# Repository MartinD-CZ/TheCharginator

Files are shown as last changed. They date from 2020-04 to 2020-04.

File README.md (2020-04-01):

# The CHARGINATOR
*Upcycle your old ATX power supply into this 11-port QC-compatible charging monstrosity!*
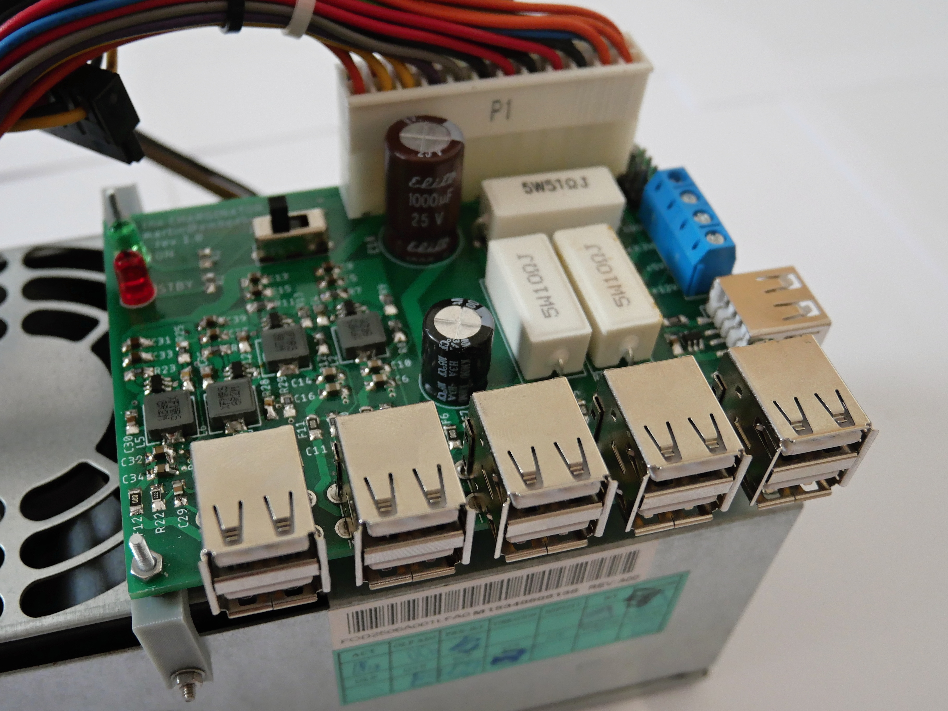
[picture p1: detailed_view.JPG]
Detailed view


Features:
* connects to an old PC power supply via a 24-pin MOLEX Mini-fit Jr. connector.
* provides power-on switch and LED, stand-by LED and three load resistors.
* 4 USB ports, compatible with QC3.0 (up to 24 W per port, 12 V 2 A), FCP (Huawei), DCP (Apple) and BCP (Battery Charging Protocol).
* 6 USB ports, compatible with DCP and BCP (5 V 2 A per port).
* 1 USB stand-by port, copatible with DCP and BCP (5 V 2 A per port).
* Each output individually fused with resetable fuse.
* Also, screw terminals with 3.3, 5 and 12 V are available.

Links:
* [Hackaday article]()
* [Article on my blog, explaining how the QC part works](http://embedblog.eu/?p=504)
* [FP6601 datasheet](https://datasheet.lcsc.com/szlcsc/Fitipower-Integrated-Tech-FP6601QS6_C86198.pdf)

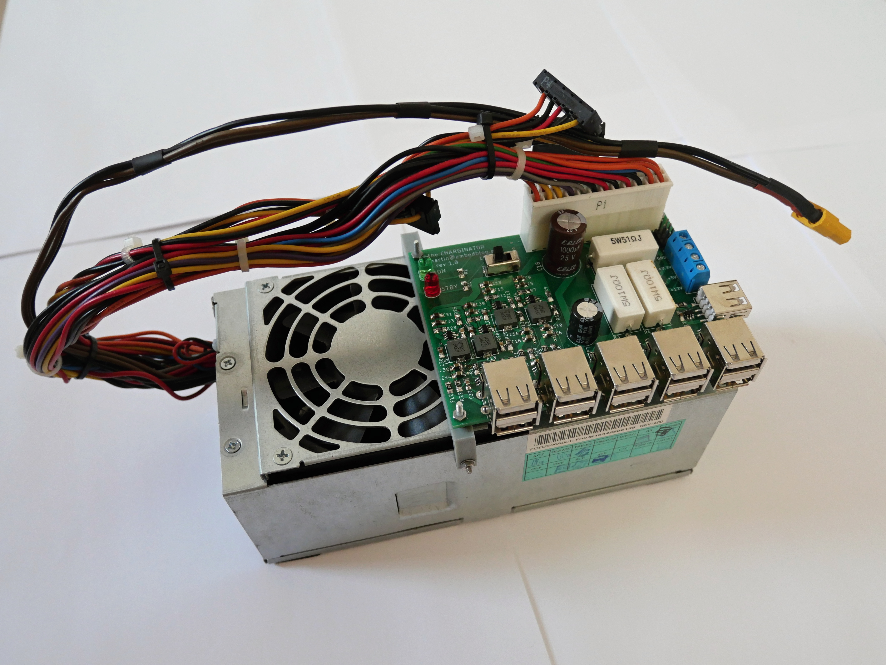
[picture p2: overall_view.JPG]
Overall view


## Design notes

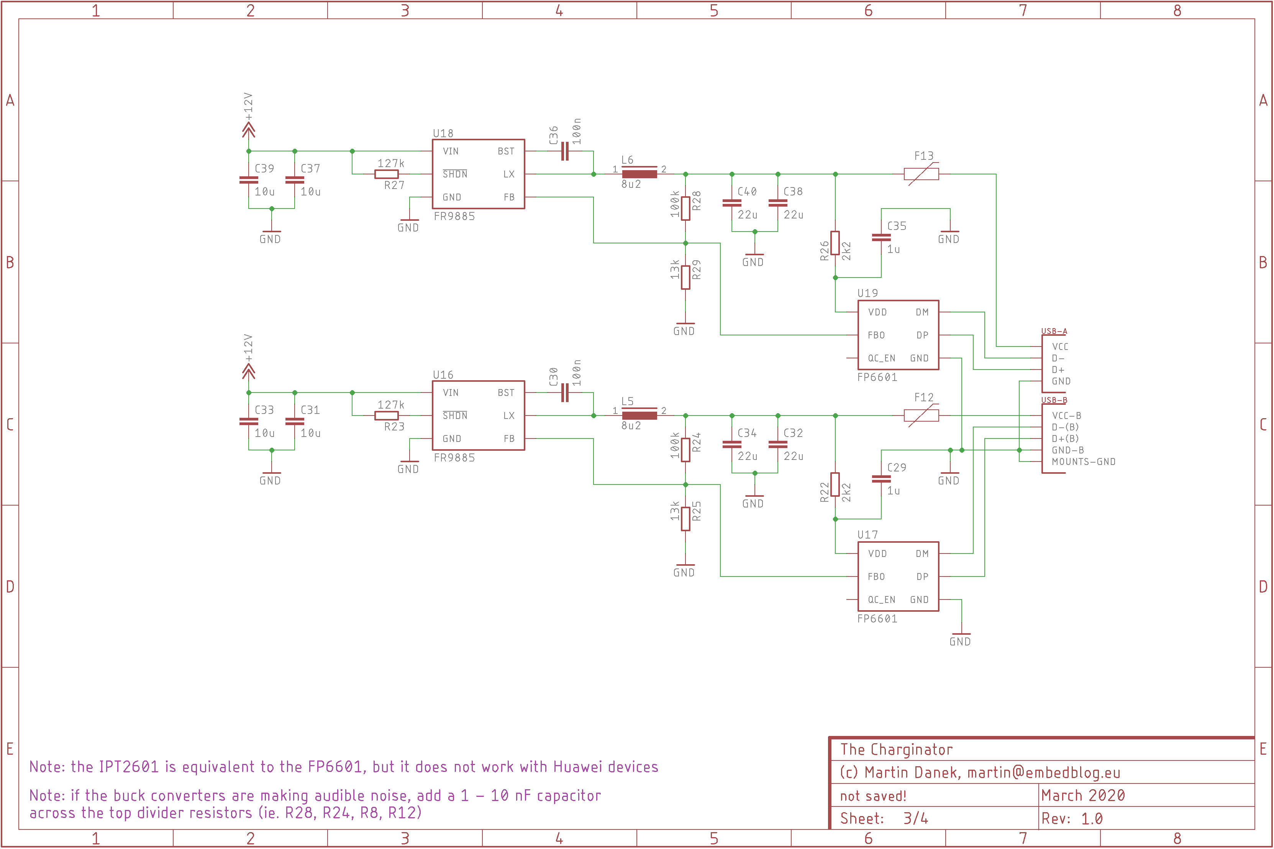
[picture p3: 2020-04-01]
schematics_png/sheet3.png

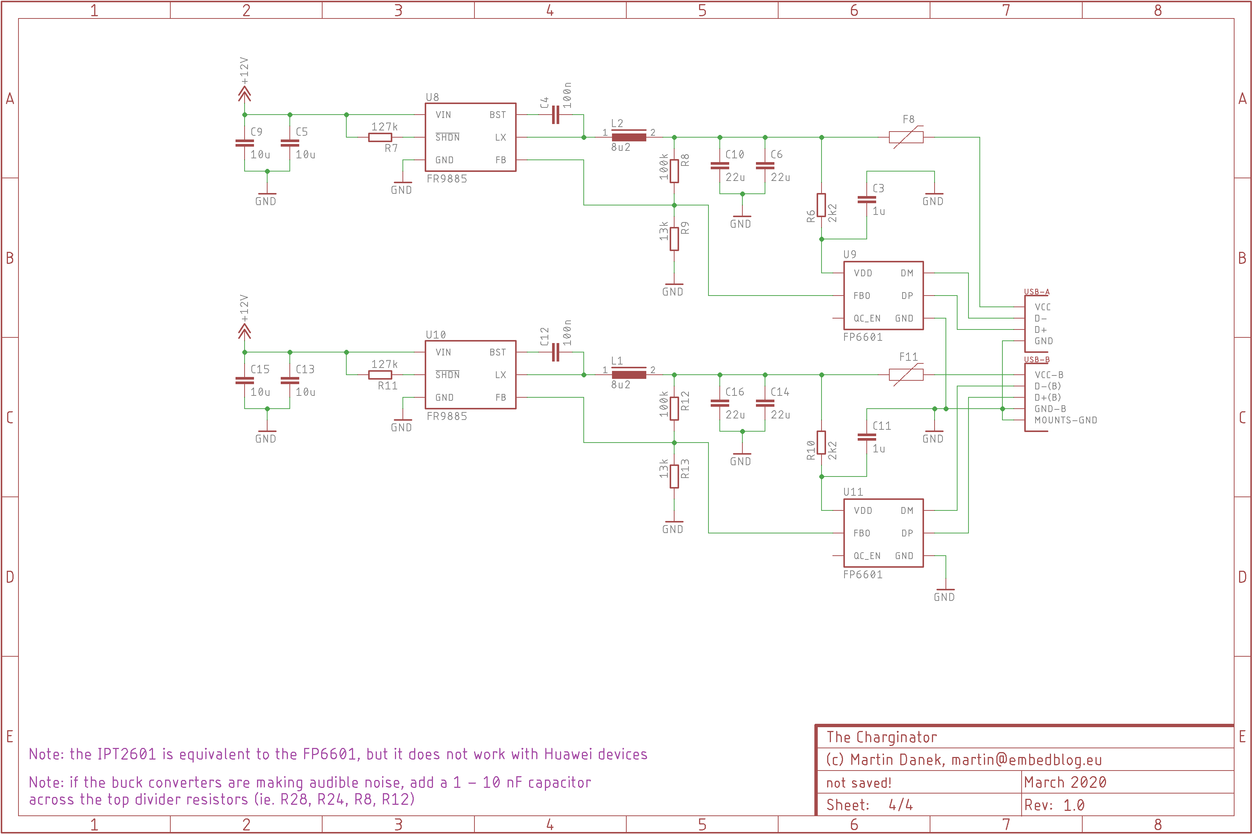
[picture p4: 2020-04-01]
schematics_png/sheet4.png

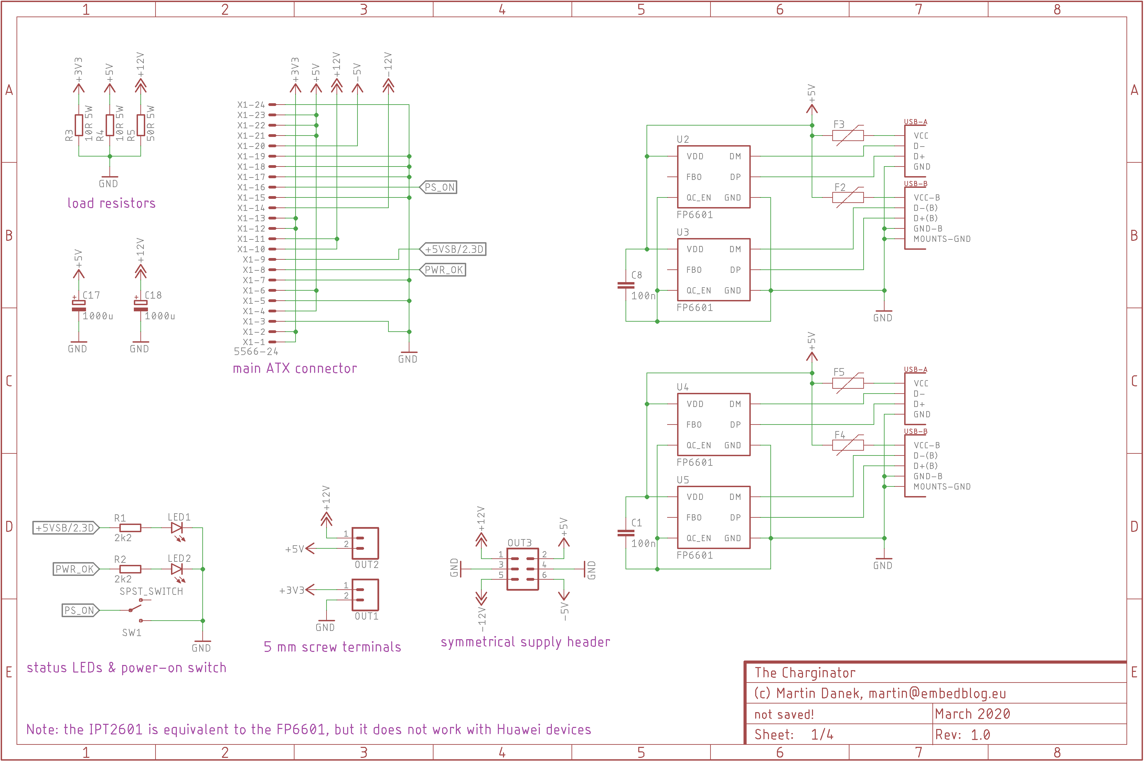
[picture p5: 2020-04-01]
schematics_png/sheet1.png

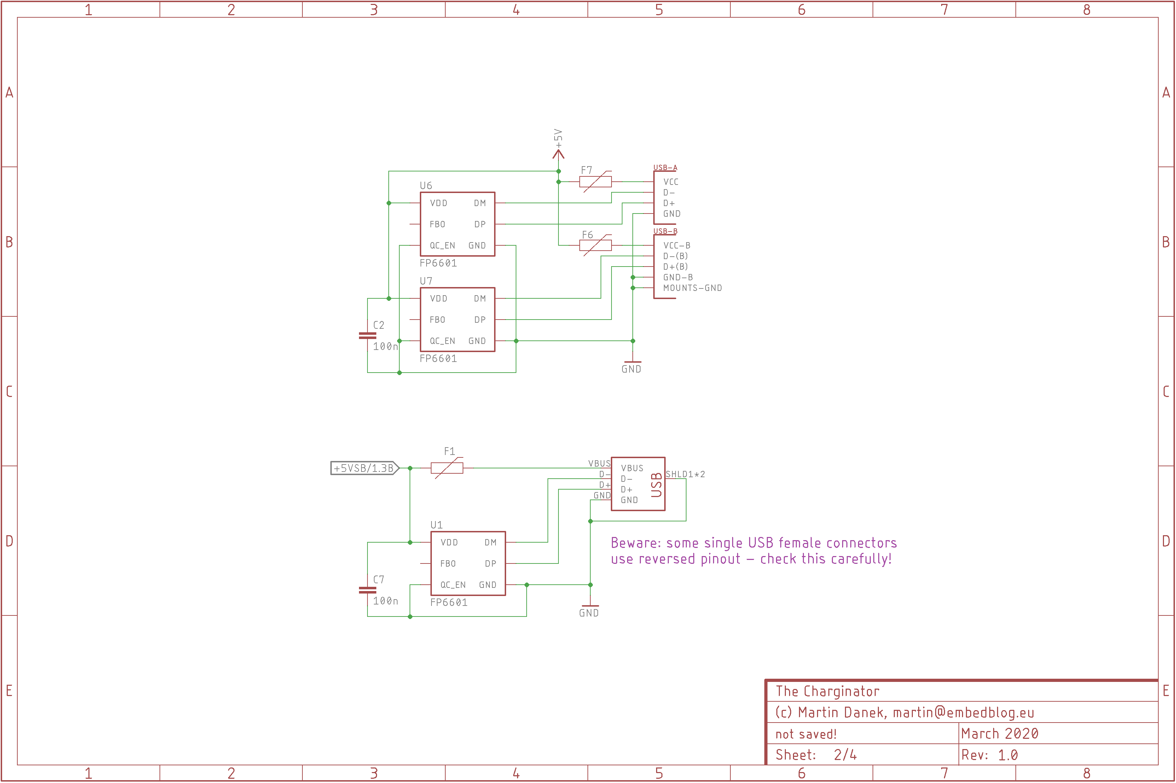
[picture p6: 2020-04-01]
schematics_png/sheet2.png

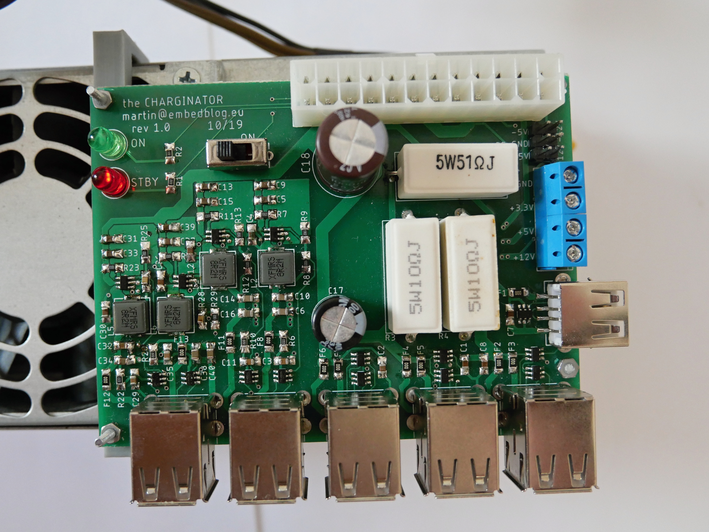
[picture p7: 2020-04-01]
top_view.JPG

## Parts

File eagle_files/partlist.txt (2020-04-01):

Partlist

Exported from charginator_v1.sch at 01.04.2020 11:05

EAGLE Version 9.3.0 Copyright (c) 1988-2019 Autodesk, Inc.

Assembly variant: 

Part     Value                   Device                  Package             Library             Sheet

C1       100n                    C-EUC1206               C1206               resistor            1
C2       100n                    C-EUC1206               C1206               resistor            2
C3       1u                      C-EUC1206               C1206               resistor            4
C4       100n                    C-EUC1206               C1206               resistor            4
C5       10u                     C-EUC1206               C1206               resistor            4
C6       22u                     C-EUC1206               C1206               resistor            4
C7       100n                    C-EUC1206               C1206               resistor            2
C8       100n                    C-EUC1206               C1206               resistor            1
C9       10u                     C-EUC1206               C1206               resistor            4
C10      22u                     C-EUC1206               C1206               resistor            4
C11      1u                      C-EUC1206               C1206               resistor            4
C12      100n                    C-EUC1206               C1206               resistor            4
C13      10u                     C-EUC1206               C1206               resistor            4
C14      22u                     C-EUC1206               C1206               resistor            4
C15      10u                     C-EUC1206               C1206               resistor            4
C16      22u                     C-EUC1206               C1206               resistor            4
C17      1000u                   CPOL-EUE5-10.5          E5-10,5             resistor            1
C18      1000u                   CPOL-EUE5-13            E5-13               resistor            1
C29      1u                      C-EUC1206               C1206               resistor            3
C30      100n                    C-EUC1206               C1206               resistor            3
C31      10u                     C-EUC1206               C1206               resistor            3
C32      22u                     C-EUC1206               C1206               resistor            3
C33      10u                     C-EUC1206               C1206               resistor            3
C34      22u                     C-EUC1206               C1206               resistor            3
C35      1u                      C-EUC1206               C1206               resistor            3
C36      100n                    C-EUC1206               C1206               resistor            3
C37      10u                     C-EUC1206               C1206               resistor            3
C38      22u                     C-EUC1206               C1206               resistor            3
C39      10u                     C-EUC1206               C1206               resistor            3
C40      22u                     C-EUC1206               C1206               resistor            3
F1       6V/2A                   PPTC_HALF-AMP           1206                SparkFun-Fuses      2
F2       6V/2A                   PPTC_HALF-AMP           1206                SparkFun-Fuses      1
F3       6V/2A                   PPTC_HALF-AMP           1206                SparkFun-Fuses      1
F4       6V/2A                   PPTC_HALF-AMP           1206                SparkFun-Fuses      1
F5       6V/2A                   PPTC_HALF-AMP           1206                SparkFun-Fuses      1
F6       6V/2A                   PPTC_HALF-AMP           1206                SparkFun-Fuses      2
F7       6V/2A                   PPTC_HALF-AMP           1206                SparkFun-Fuses      2
F8       12V/2A                  PPTC_HALF-AMP           1206                SparkFun-Fuses      4
F11      12V/2A                  PPTC_HALF-AMP           1206                SparkFun-Fuses      4
F12      12V/2A                  PPTC_HALF-AMP           1206                SparkFun-Fuses      3
F13      12V/2A                  PPTC_HALF-AMP           1206                SparkFun-Fuses      3
L1       8u2                     DR73                    DR73                inductors           4
L2       8u2                     DR73                    DR73                inductors           4
L5       8u2                     DR73                    DR73                inductors           3
L6       8u2                     DR73                    DR73                inductors           3
LED1                             LED5MM                  LED5MM              led                 1
LED2                             LED5MM                  LED5MM              led                 1
OUT1     5MM_SCREWTERMINAL_LARGE 5MM_SCREWTERMINAL_LARGE SCREWTERMINAL-5MM-2 custom              1
OUT2     5MM_SCREWTERMINAL_LARGE 5MM_SCREWTERMINAL_LARGE SCREWTERMINAL-5MM-2 custom              1
OUT3     FEMALE 2x3              CONN_03X2FEMALE         2X3                 SparkFun-Connectors 1
R1       2k2                     R-EU_M1206              M1206               resistor            1
R2       2k2                     R-EU_M1206              M1206               resistor            1
R3       10R 5W                  RESISTOR_5W             POWER_RESISTOR_5W   custom              1
R4       10R 5W                  RESISTOR_5W             POWER_RESISTOR_5W   custom              1
R5       50R 5W                  RESISTOR_5W             POWER_RESISTOR_5W   custom              1
R6       2k2                     R-EU_R1206              R1206               resistor            4
R7       127k                    R-EU_R1206              R1206               resistor            4
R8       100k                    R-EU_R1206              R1206               resistor            4
R9       13k                     R-EU_R1206              R1206               resistor            4
R10      2k2                     R-EU_R1206              R1206               resistor            4
R11      127k                    R-EU_R1206              R1206               resistor            4
R12      100k                    R-EU_R1206              R1206               resistor            4
R13      13k                     R-EU_R1206              R1206               resistor            4
R22      2k2                     R-EU_R1206              R1206               resistor            3
R23      127k                    R-EU_R1206              R1206               resistor            3
R24      100k                    R-EU_R1206              R1206               resistor            3
R25      13k                     R-EU_R1206              R1206               resistor            3
R26      2k2                     R-EU_R1206              R1206               resistor            3
R27      127k                    R-EU_R1206              R1206               resistor            3
R28      100k                    R-EU_R1206              R1206               resistor            3
R29      13k                     R-EU_R1206              R1206               resistor            3
SW1      SPST_SWITCH             SPST_SWITCH             TL3XYO              custom              1
U$1      DUAL-PORT-USB-REC       DUAL-PORT-USB-REC       DUAL-PORT-USB       tps2511             1
U$2      DUAL-PORT-USB-REC       DUAL-PORT-USB-REC       DUAL-PORT-USB       tps2511             1
U$3      DUAL-PORT-USB-REC       DUAL-PORT-USB-REC       DUAL-PORT-USB       tps2511             2
U$4      DUAL-PORT-USB-REC       DUAL-PORT-USB-REC       DUAL-PORT-USB       tps2511             4
U$5      USB_A_REVERSED          USB_A_REVERSED          USB-A-S-SILK-FEMALE custom              2
U$6      DUAL-PORT-USB-REC       DUAL-PORT-USB-REC       DUAL-PORT-USB       tps2511             3
U1       FP6601                  IPT2601                 SOT23-6             custom              2
U2       FP6601                  IPT2601                 SOT23-6             custom              1
U3       FP6601                  IPT2601                 SOT23-6             custom              1
U4       FP6601                  IPT2601                 SOT23-6             custom              1
U5       FP6601                  IPT2601                 SOT23-6             custom              1
U6       FP6601                  IPT2601                 SOT23-6             custom              2
U7       FP6601                  IPT2601                 SOT23-6             custom              2
U8       FR9885                  FR9885                  SOT23-6             custom              4
U9       FP6601                  IPT2601                 SOT23-6             custom              4
U10      FR9885                  FR9885                  SOT23-6             custom              4
U11      FP6601                  IPT2601                 SOT23-6             custom              4
U16      FR9885                  FR9885                  SOT23-6             custom              3
U17      FP6601                  IPT2601                 SOT23-6             custom              3
U18      FR9885                  FR9885                  SOT23-6             custom              3
U19      FP6601                  IPT2601                 SOT23-6             custom              3
X1       5566-24                 5566-24                 5566-24             con-molex           1

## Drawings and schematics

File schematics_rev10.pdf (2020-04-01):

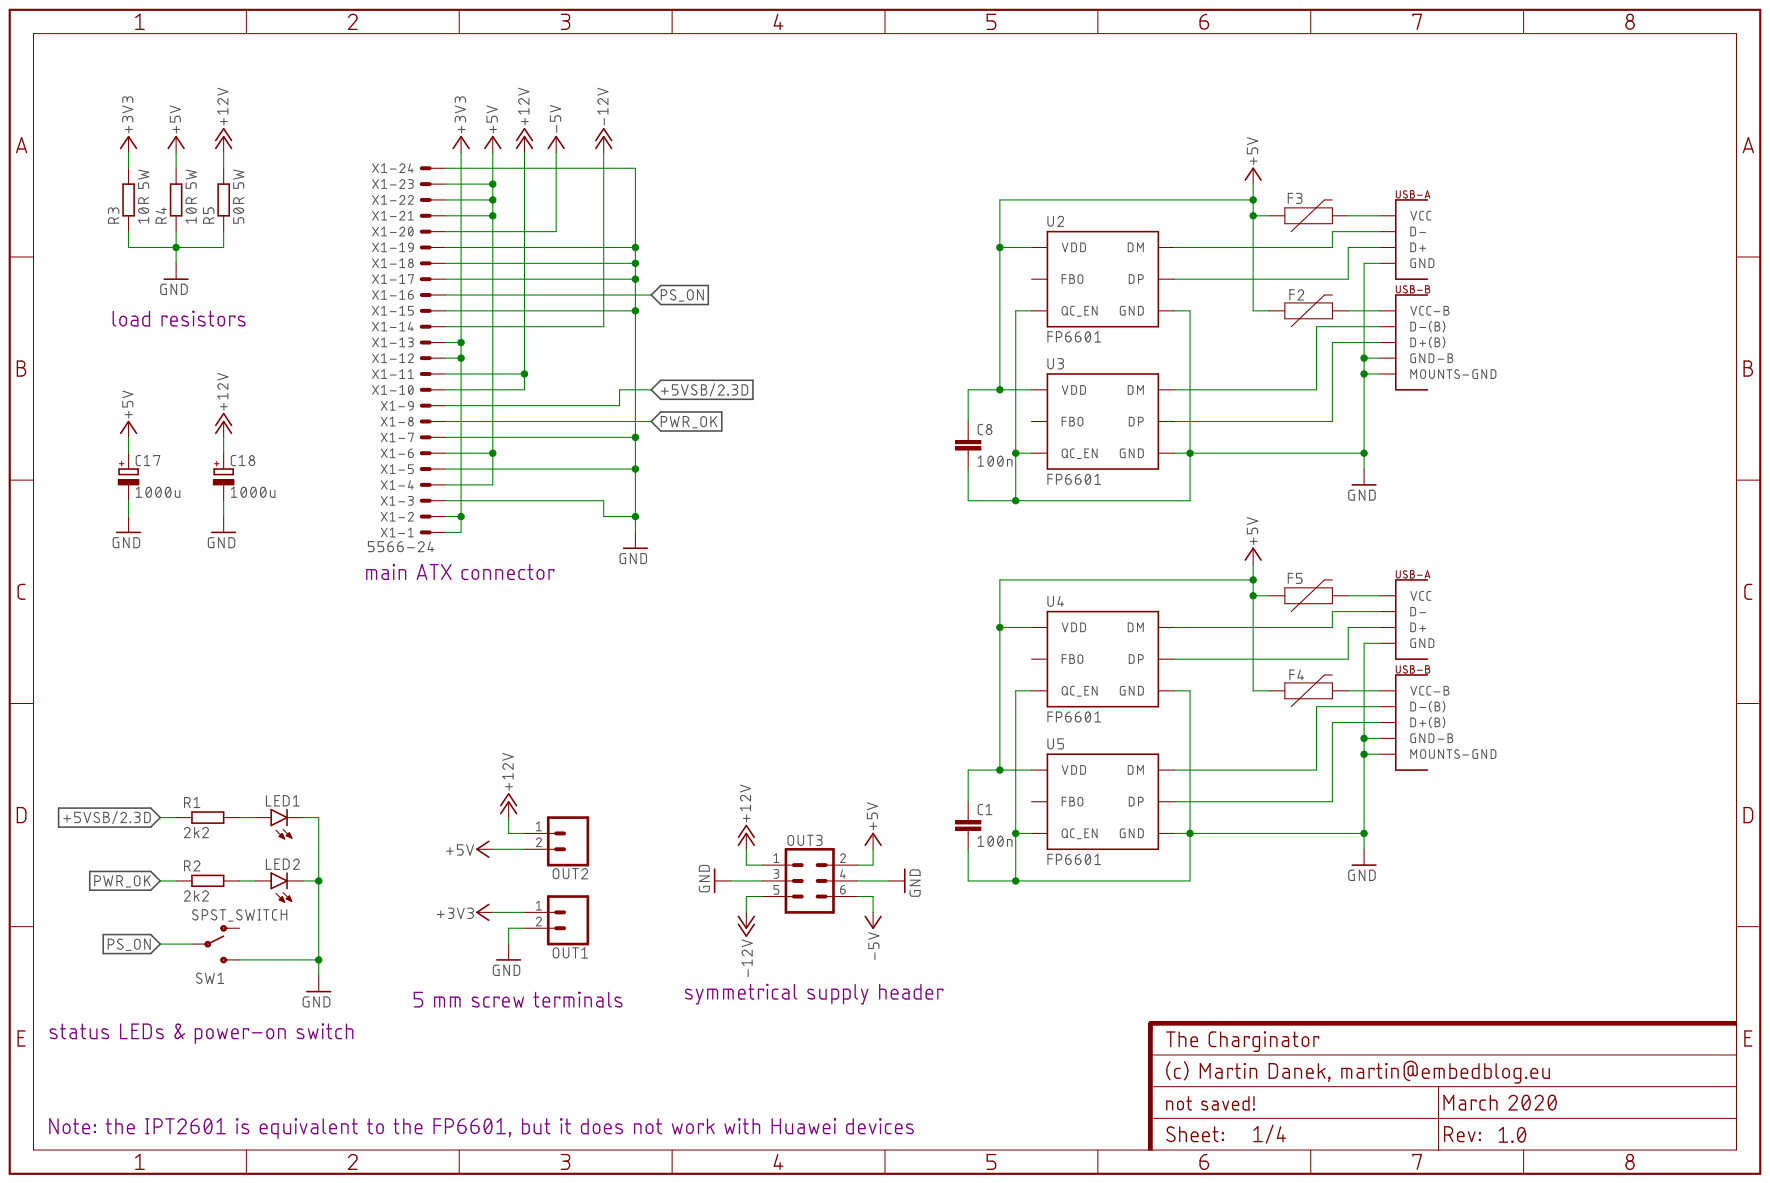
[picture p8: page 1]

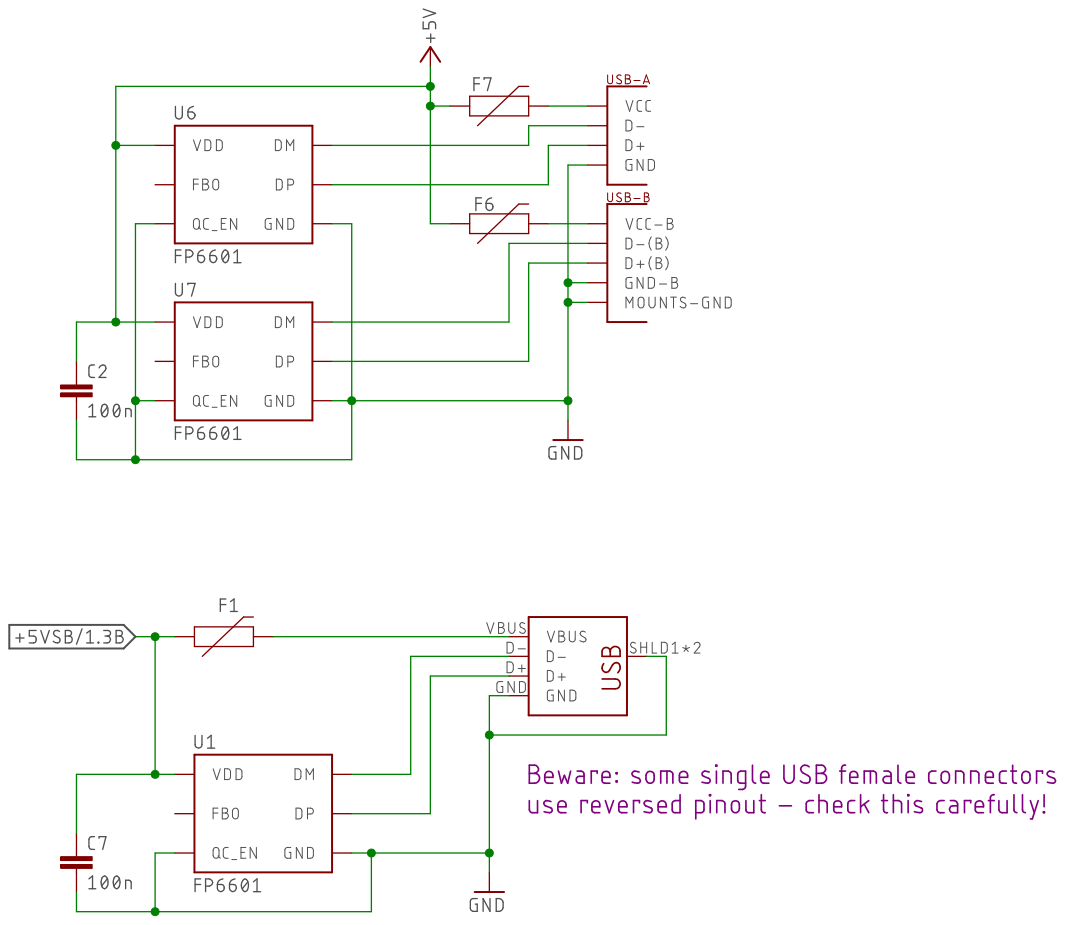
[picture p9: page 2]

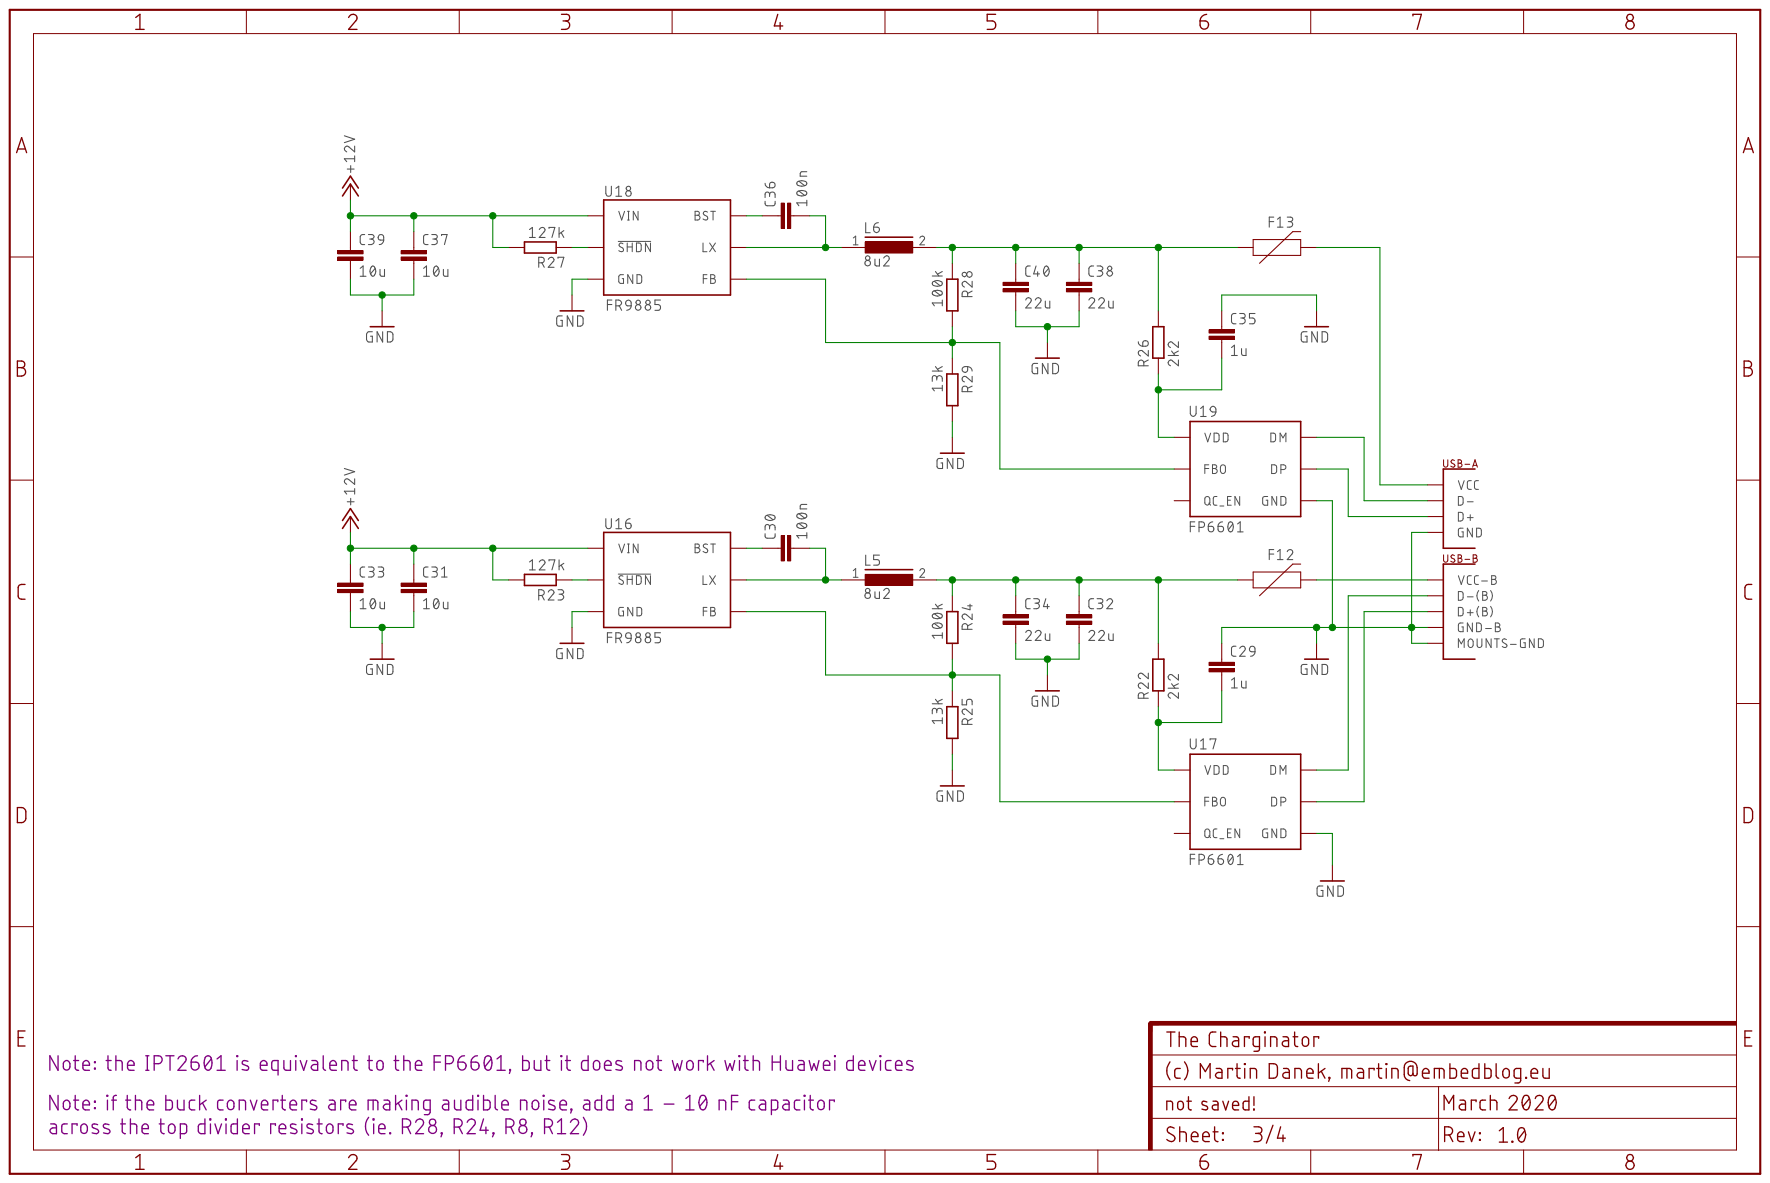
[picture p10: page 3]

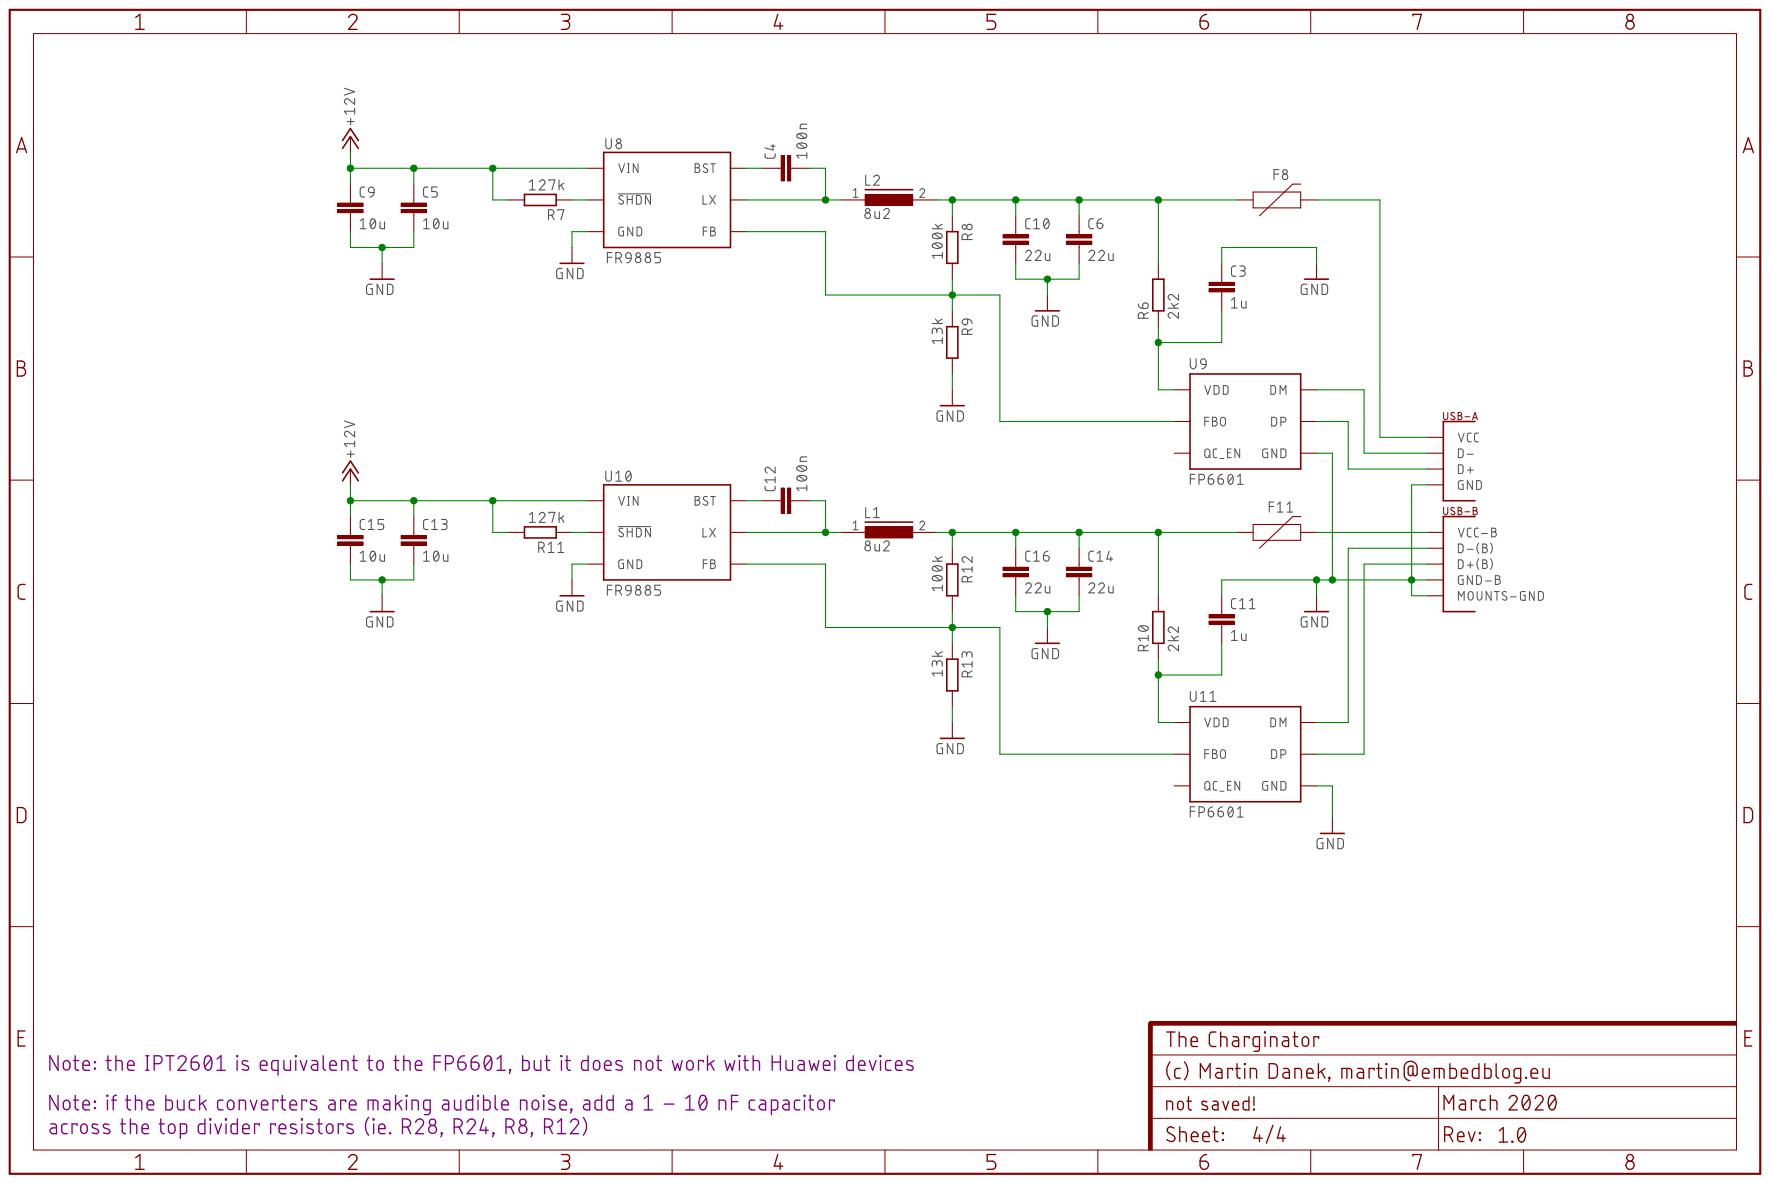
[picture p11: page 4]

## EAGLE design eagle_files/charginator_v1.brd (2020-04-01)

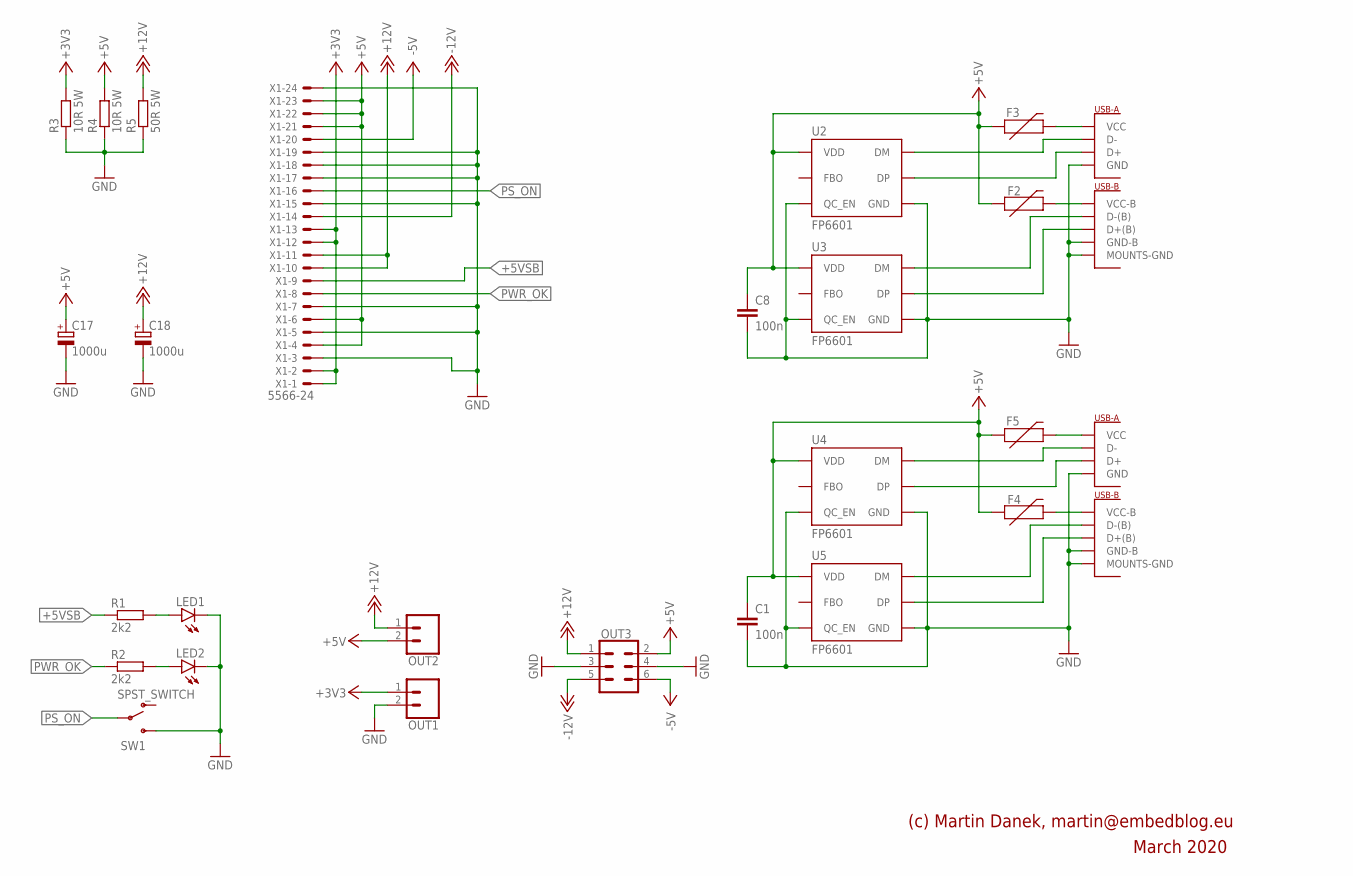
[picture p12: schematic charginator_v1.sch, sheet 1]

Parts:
C1, C8: 100n; C1206
C17: 1000u; E5-10,5
C18: 1000u; E5-13
F2, F3, F4, F5: 6V/2A; 1206
LED1, LED2: LED5MM
OUT1, OUT2: 5MM_SCREWTERMINAL_LARGE; SCREWTERMINAL-5MM-2
OUT3: FEMALE 2x3; 2X3
R1, R2: 2k2; M1206
R3, R4: 10R 5W; POWER_RESISTOR_5W
R5: 50R 5W; POWER_RESISTOR_5W
SW1: SPST_SWITCH; TL3XYO
U2, U3, U4, U5: FP6601; SOT23-6
U$1, U$2: DUAL-PORT-USB-REC; DUAL-PORT-USB
X1: 5566-24

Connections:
+3V3: OUT1.1, R3.P$2 (2), X1.1, X1.2, X1.12, X1.13
+5V: C1.1, C8.1, C17.+, F2.1, F3.1, F4.1, F5.1, OUT2.2, OUT3.2, R4.P$2 (2), U2.5 (VDD), U3.5 (VDD), U4.5 (VDD), U5.5 (VDD), X1.4, X1.6, X1.21, X1.22, X1.23; also elsewhere on the board
+5VSB: R1.1, X1.9; also elsewhere on the board
+12V: C18.+, OUT2.1, OUT3.1, R5.P$2 (2), X1.10, X1.11; also elsewhere on the board
-5V: OUT3.6, X1.20
-12V: OUT3.5, X1.14
GND: C1.2, C8.2, C17.-, C18.-, LED1.K (C), LED2.K (C), OUT1.2, OUT3.3, OUT3.4, R3.P$1 (1), R4.P$1 (1), R5.P$1 (1), SW1.1 (S), U2.2 (GND), U2.4 (QC_EN), U3.2 (GND), U3.4 (QC_EN), U4.2 (GND), U4.4 (QC_EN), U5.2 (GND), U5.4 (QC_EN), U$1.GND (MOUNTS-GND), U$1.P$2 (MOUNTS-GND), U$1.P$3 (MOUNTS-GND), U$1.P$4 (MOUNTS-GND), U$1.P$9 (GND-B), U$1.P$11 (GND), U$2.GND (MOUNTS-GND), U$2.P$2 (MOUNTS-GND), U$2.P$3 (MOUNTS-GND), U$2.P$4 (MOUNTS-GND), U$2.P$9 (GND-B), U$2.P$11 (GND), X1.3, X1.5, X1.7, X1.15, X1.17, X1.18, X1.19, X1.24; also elsewhere on the board
unnamed: LED1.A, R1.2
unnamed: LED2.A, R2.2
unnamed: F4.2, U$2.P$10 (VCC-B)
unnamed: F5.2, U$2.P$12 (VCC)
unnamed: F2.2, U$1.P$10 (VCC-B)
unnamed: F3.2, U$1.P$12 (VCC)
unnamed: U2.6 (DM), U$1.P$7 (D-)
unnamed: U2.1 (DP), U$1.P$8 (D+)
unnamed: U4.6 (DM), U$2.P$7 (D-)
unnamed: U4.1 (DP), U$2.P$8 (D+)
unnamed: U5.6 (DM), U$2.P$5 (D-(B))
unnamed: U5.1 (DP), U$2.P$6 (D+(B))
unnamed: U3.6 (DM), U$1.P$5 (D-(B))
unnamed: U3.1 (DP), U$1.P$6 (D+(B))
PS_ON: SW1.2, X1.16
PWR_OK: R2.1, X1.8

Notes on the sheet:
(c) Martin Danek, martin@embedblog.eu
March 2020

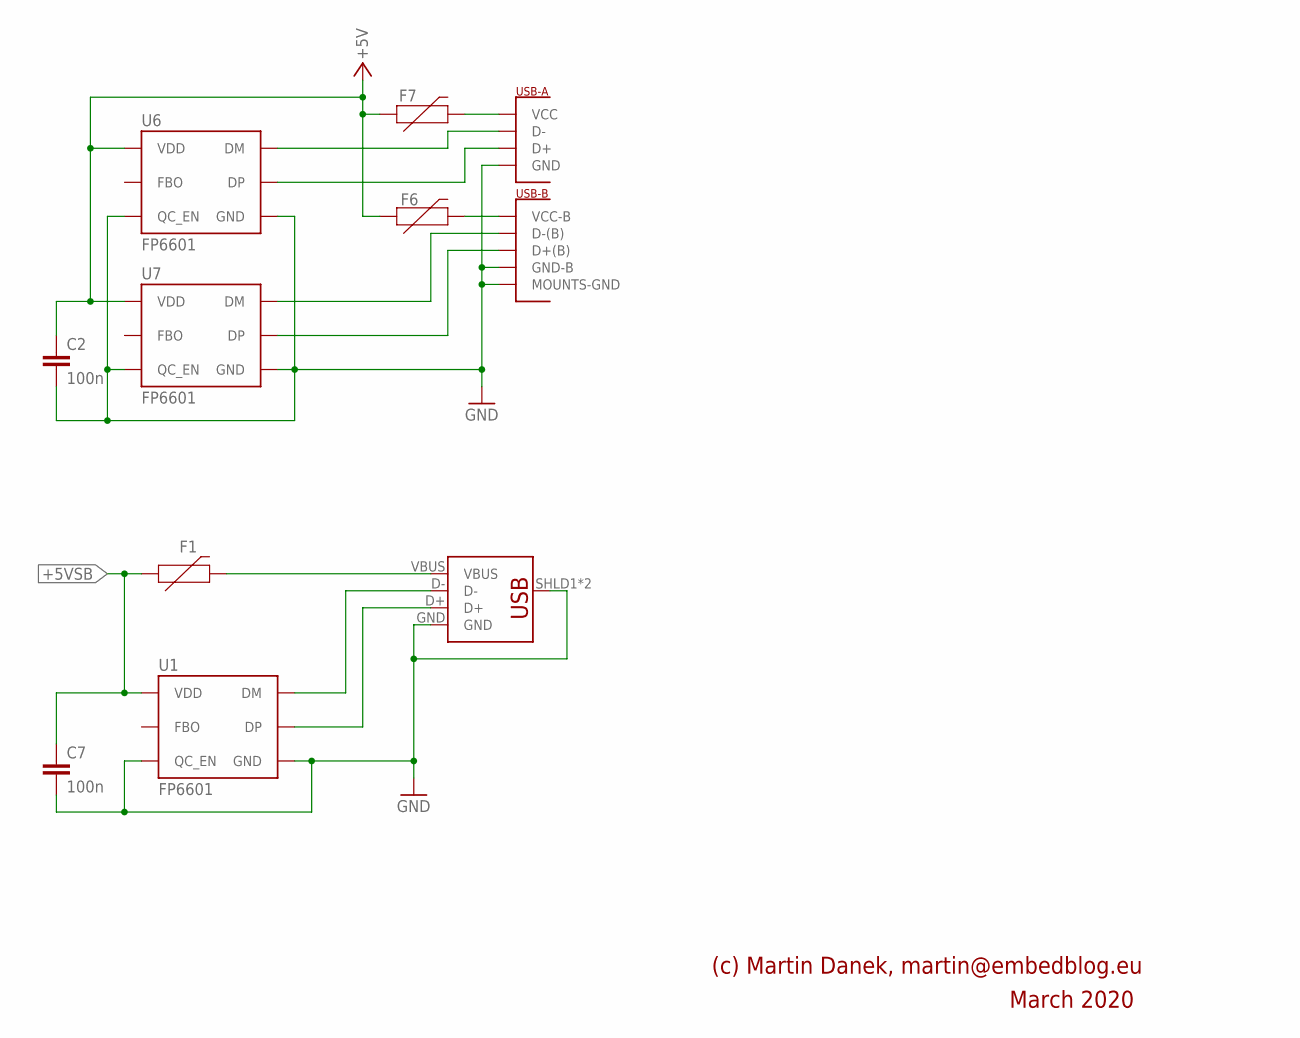
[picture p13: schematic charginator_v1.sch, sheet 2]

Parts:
C2, C7: 100n; C1206
F1, F6, F7: 6V/2A; 1206
U1, U6, U7: FP6601; SOT23-6
U$3: DUAL-PORT-USB-REC; DUAL-PORT-USB
U$5: USB_A_REVERSED; USB-A-S-SILK-FEMALE

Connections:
+5V: C2.1, F6.1, F7.1, U6.5 (VDD), U7.5 (VDD); also elsewhere on the board
+5VSB: C7.1, F1.1, U1.5 (VDD); also elsewhere on the board
GND: C2.2, C7.2, U1.2 (GND), U1.4 (QC_EN), U6.2 (GND), U6.4 (QC_EN), U7.2 (GND), U7.4 (QC_EN), U$3.GND (MOUNTS-GND), U$3.P$2 (MOUNTS-GND), U$3.P$3 (MOUNTS-GND), U$3.P$4 (MOUNTS-GND), U$3.P$9 (GND-B), U$3.P$11 (GND), U$5.GND, U$5.SHLD1 (SHIELD), U$5.SHLD2 (SHIELD); also elsewhere on the board
unnamed: F1.2, U$5.VBUS
unnamed: U1.6 (DM), U$5.D-
unnamed: F6.2, U$3.P$10 (VCC-B)
unnamed: U1.1 (DP), U$5.D+
unnamed: F7.2, U$3.P$12 (VCC)
unnamed: U6.6 (DM), U$3.P$7 (D-)
unnamed: U6.1 (DP), U$3.P$8 (D+)
unnamed: U7.6 (DM), U$3.P$5 (D-(B))
unnamed: U7.1 (DP), U$3.P$6 (D+(B))

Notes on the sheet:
(c) Martin Danek, martin@embedblog.eu
March 2020

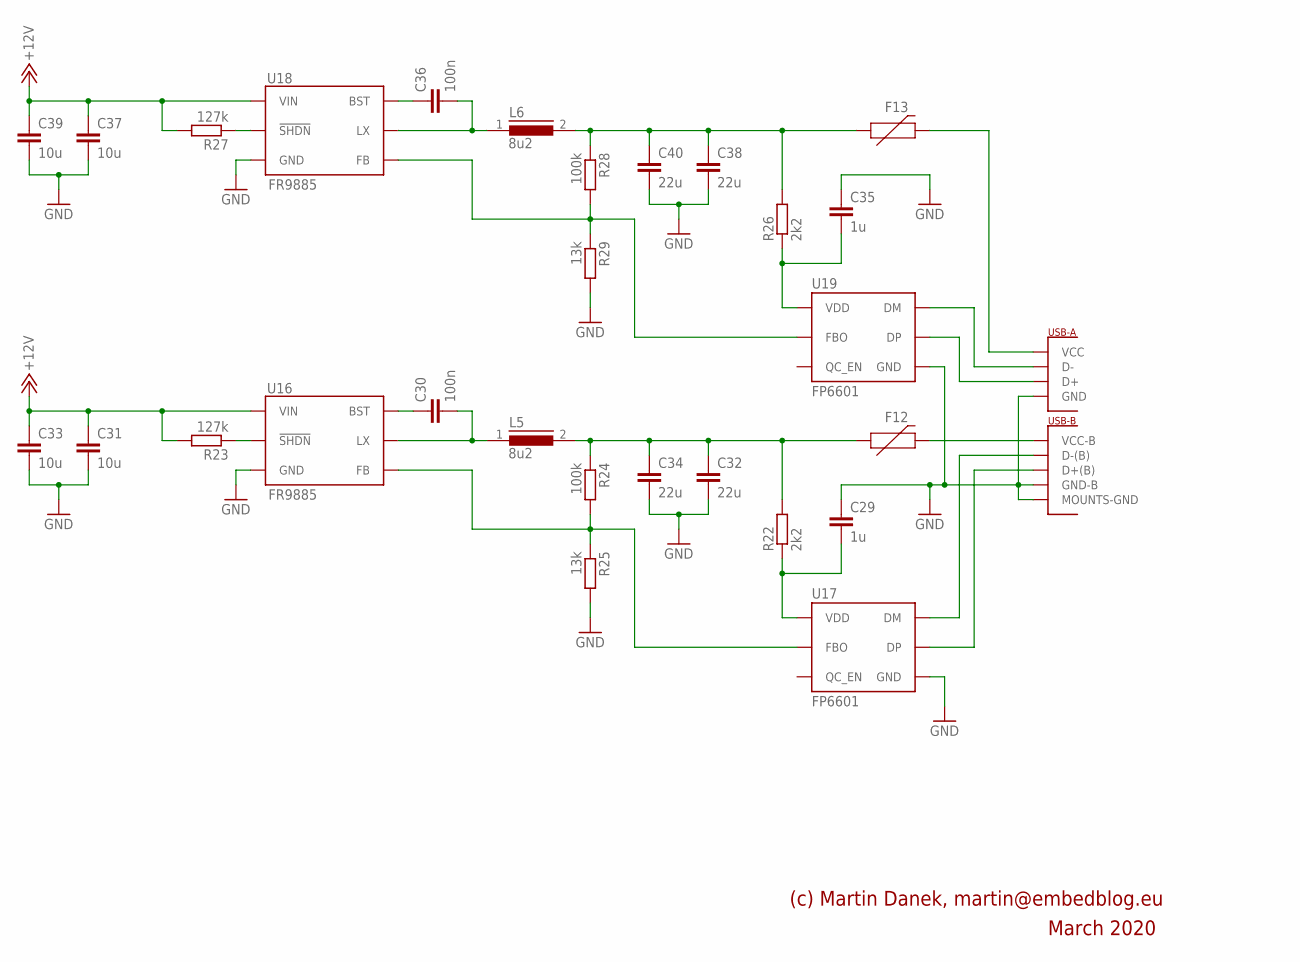
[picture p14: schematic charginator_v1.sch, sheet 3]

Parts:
C29, C35: 1u; C1206
C30, C36: 100n; C1206
C31, C33, C37, C39: 10u; C1206
C32, C34, C38, C40: 22u; C1206
F12, F13: 12V/2A; 1206
L5, L6: 8u2; DR73
R22, R26: 2k2; R1206
R23, R27: 127k; R1206
R24, R28: 100k; R1206
R25, R29: 13k; R1206
U16, U18: FR9885; SOT23-6
U17, U19: FP6601; SOT23-6
U$6: DUAL-PORT-USB-REC; DUAL-PORT-USB

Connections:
+12V: C31.1, C33.1, C37.1, C39.1, R23.2, R27.2, U16.5 (VIN), U18.5 (VIN); also elsewhere on the board
FB5: R24.2, R25.1, U16.3 (FB), U17.3 (FBO)
FB6: R28.2, R29.1, U18.3 (FB), U19.3 (FBO)
GND: C29.1, C31.2, C32.2, C33.2, C34.2, C35.1, C37.2, C38.2, C39.2, C40.2, R25.2, R29.2, U16.2 (GND), U17.2 (GND), U18.2 (GND), U19.2 (GND), U$6.GND (MOUNTS-GND), U$6.P$2 (MOUNTS-GND), U$6.P$3 (MOUNTS-GND), U$6.P$4 (MOUNTS-GND), U$6.P$9 (GND-B), U$6.P$11 (GND); also elsewhere on the board
LX5: C30.2, L5.1, U16.6 (LX)
LX6: C36.2, L6.1, U18.6 (LX)
unnamed: C32.1, C34.1, F12.1, L5.2, R22.2, R24.1
unnamed: C29.2, R22.1, U17.5 (VDD)
unnamed: R23.1, U16.4 (!SHDN)
unnamed: C30.1, U16.1 (BST)
unnamed: U17.6 (DM), U$6.P$5 (D-(B))
unnamed: U17.1 (DP), U$6.P$6 (D+(B))
unnamed: C38.1, C40.1, F13.1, L6.2, R26.2, R28.1
unnamed: C35.2, R26.1, U19.5 (VDD)
unnamed: R27.1, U18.4 (!SHDN)
unnamed: C36.1, U18.1 (BST)
unnamed: U19.1 (DP), U$6.P$8 (D+)
unnamed: U19.6 (DM), U$6.P$7 (D-)
unnamed: F13.2, U$6.P$12 (VCC)
VBUS3: F12.2, U$6.P$10 (VCC-B)

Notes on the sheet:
(c) Martin Danek, martin@embedblog.eu
March 2020

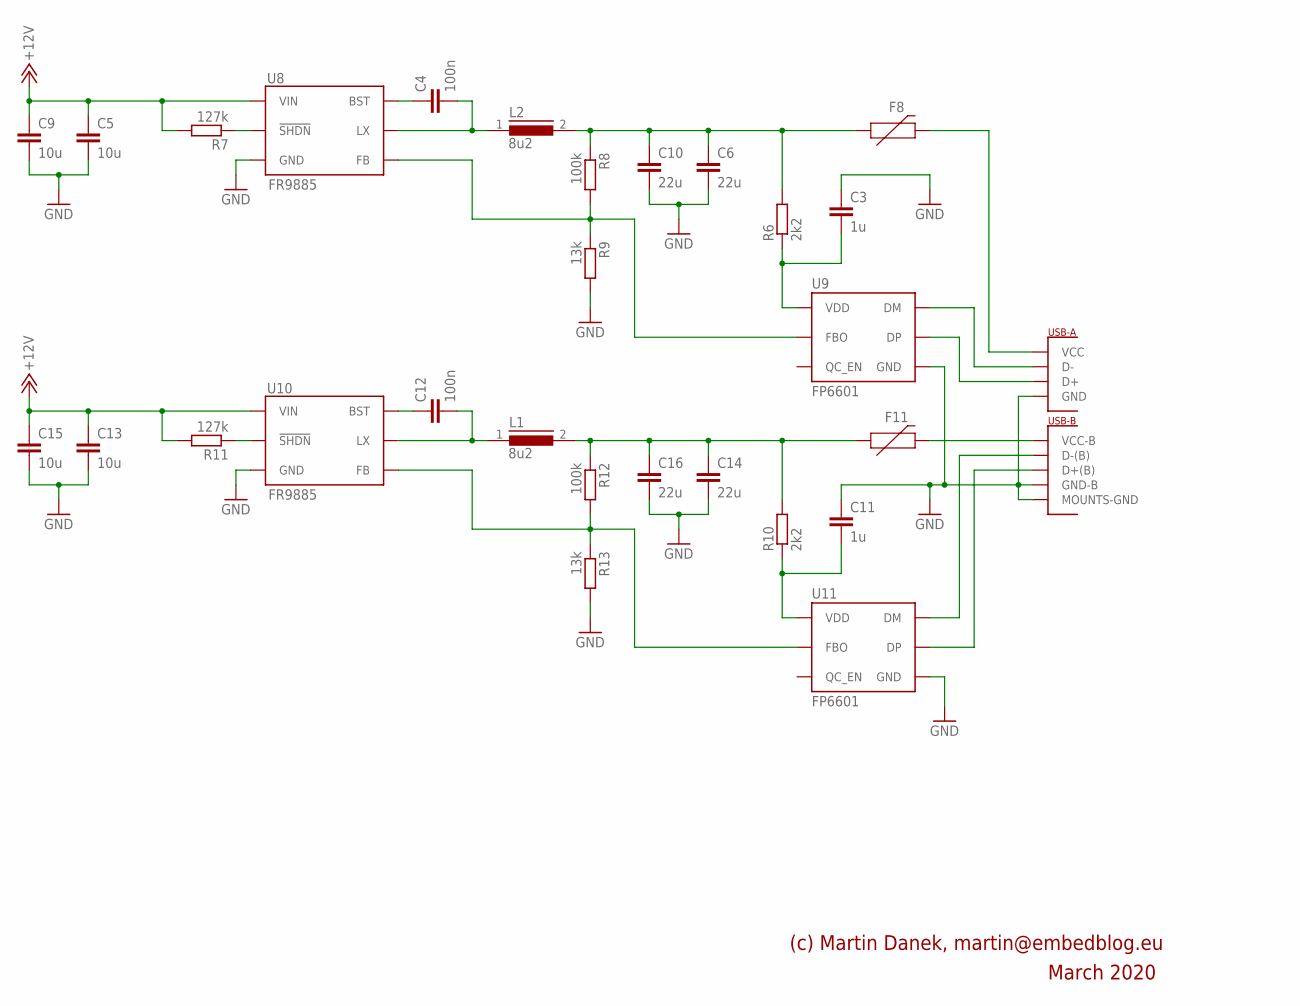
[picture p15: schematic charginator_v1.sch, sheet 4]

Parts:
C3, C11: 1u; C1206
C4, C12: 100n; C1206
C5, C9, C13, C15: 10u; C1206
C6, C10, C14, C16: 22u; C1206
F8, F11: 12V/2A; 1206
L1, L2: 8u2; DR73
R6, R10: 2k2; R1206
R7, R11: 127k; R1206
R8, R12: 100k; R1206
R9, R13: 13k; R1206
U8, U10: FR9885; SOT23-6
U9, U11: FP6601; SOT23-6
U$4: DUAL-PORT-USB-REC; DUAL-PORT-USB

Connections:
+12V: C5.1, C9.1, C13.1, C15.1, R7.2, R11.2, U8.5 (VIN), U10.5 (VIN); also elsewhere on the board
FB1: R12.2, R13.1, U10.3 (FB), U11.3 (FBO)
FB2: R8.2, R9.1, U8.3 (FB), U9.3 (FBO)
GND: C3.1, C5.2, C6.2, C9.2, C10.2, C11.1, C13.2, C14.2, C15.2, C16.2, R9.2, R13.2, U8.2 (GND), U9.2 (GND), U10.2 (GND), U11.2 (GND), U$4.GND (MOUNTS-GND), U$4.P$2 (MOUNTS-GND), U$4.P$3 (MOUNTS-GND), U$4.P$4 (MOUNTS-GND), U$4.P$9 (GND-B), U$4.P$11 (GND); also elsewhere on the board
LX1: C12.2, L1.1, U10.6 (LX)
LX2: C4.2, L2.1, U8.6 (LX)
unnamed: C6.1, C10.1, F8.1, L2.2, R6.2, R8.1
unnamed: C3.2, R6.1, U9.5 (VDD)
unnamed: R7.1, U8.4 (!SHDN)
unnamed: C4.1, U8.1 (BST)
unnamed: U9.1 (DP), U$4.P$8 (D+)
unnamed: U9.6 (DM), U$4.P$7 (D-)
unnamed: F8.2, U$4.P$12 (VCC)
unnamed: C14.1, C16.1, F11.1, L1.2, R10.2, R12.1
unnamed: C11.2, R10.1, U11.5 (VDD)
unnamed: R11.1, U10.4 (!SHDN)
unnamed: C12.1, U10.1 (BST)
unnamed: U11.6 (DM), U$4.P$5 (D-(B))
unnamed: U11.1 (DP), U$4.P$6 (D+(B))
VBUS1: F11.2, U$4.P$10 (VCC-B)

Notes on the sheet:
(c) Martin Danek, martin@embedblog.eu
March 2020

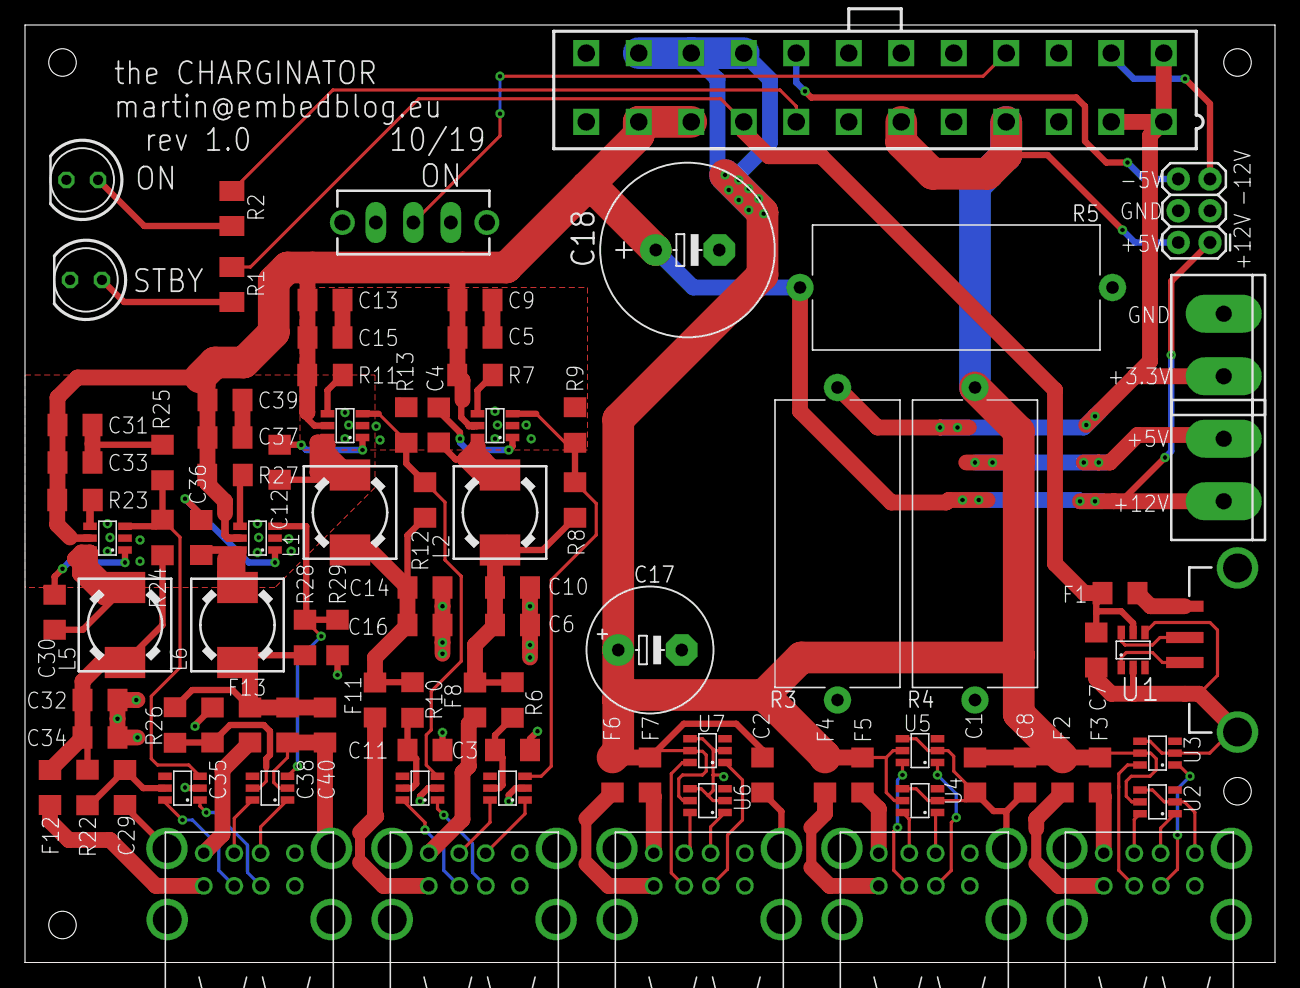
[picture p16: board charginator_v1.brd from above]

Board: 2 copper layers, 100.0 x 75.0 mm, 94 parts (0 on the bottom side), 68 nets.

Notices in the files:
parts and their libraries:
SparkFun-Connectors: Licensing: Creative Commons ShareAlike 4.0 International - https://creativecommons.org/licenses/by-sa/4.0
